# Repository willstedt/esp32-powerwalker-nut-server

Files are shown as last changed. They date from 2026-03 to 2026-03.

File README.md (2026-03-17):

# BlueWalker Online
**BlueWalker Online** konverterar en ESP32-S3 till en NUT-server för Powerwalker UPS.  Då kan Unifi läsa UPS-data och alla datorer i nätverket kan ta del av UPS-information.

# Vad som behövs för att sätta upp en NUT-server
Du behöver ha en ESP32-S3 med dubbla USB-portar  
Den väntra USB-porten används för att ge ström och ladda upp projekt-uppdateringar.  
Den högra USB-porten används för att läsa data från Powerwalkern.

**Viktigt:** Du behöver löda +5V från ESP32:an till de stora benen till höger eller vänster på ESP32:ans högra USB-port eftersom ESP32 inte skickar ut 5V till USB-porten (den är USB-slav och det är bara USB-masters som skickar ut 5V). Därför behöver du ta 5V från ESP32 och skicka ut på ena benet.

Montera en liten OLED-skärm 128x64 (med fyra pinnar: 3V3, GND, SDA och SCL). Den visar vilken IP-adress enheten fått samt batteriprocent.  

`SDA = GPIO 8`  
`SCL = GPIO 9`

Montera en liten tryckknapp för att resetta enheten, samt i framtiden kunna ändra wifi-inställningar etc.
Tryckknappen ska kopplas mot `SDA = GPIO 10` och `GND`.  
  
STL för att 3D-printa box och lock:  
[Box](BlueWalker Connect Case.stl)  
[Lock](Bluewalker Connect Lid.stl)  

# Användning
**NUT:** UPS-servern använder sig av NUT (Network UPS Tools) som gör att enheter på nätverket kan få information från UPS:en.

För att kunna läsa UPS-information från NUT-servern – installera **nut** (`brew install nut`).
För att Mac ska övervaka UPS via NUT, kör `upsc ups@[IP]`. Exempelvis `upsc ups@10.21.0.136`.

**SNMP:** Enheten har också en SNMP-agent på port 161 som gör att Unifi och andra enheter som scannar SNMP automatiskt kan hitta den.

**WEBB:** BlueWalker Online har också en inbyggd webbserver så att du kan få information via en vanlig webbläsare.

**Komplett enhet:**  
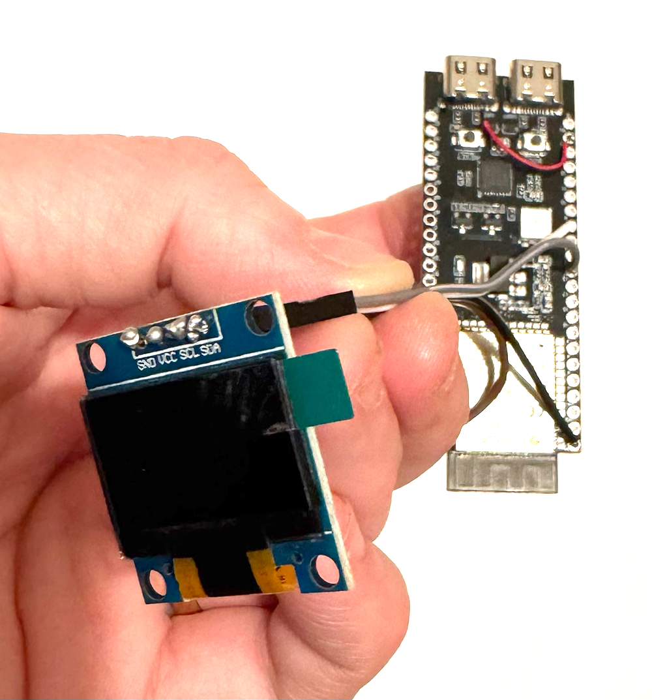
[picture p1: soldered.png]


**Lödning:**  
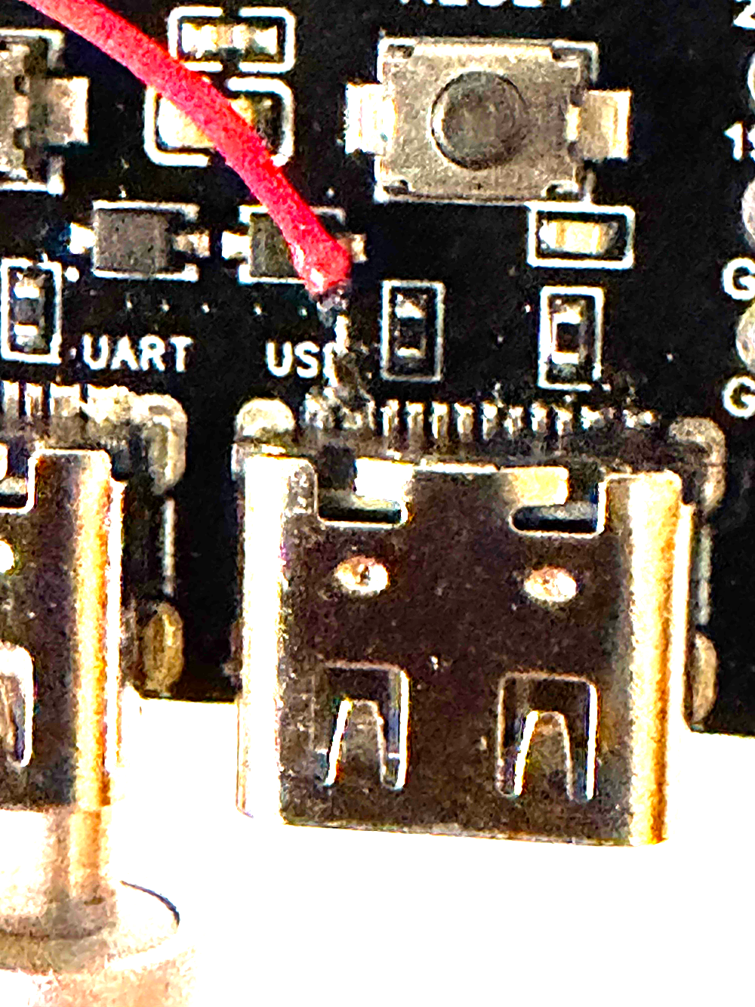
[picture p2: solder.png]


**Enhet:**  
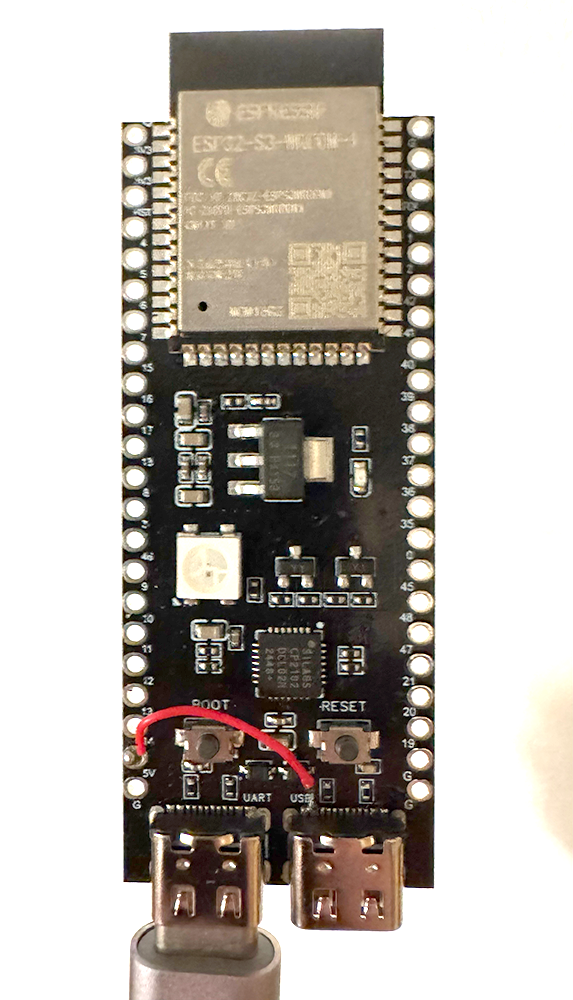
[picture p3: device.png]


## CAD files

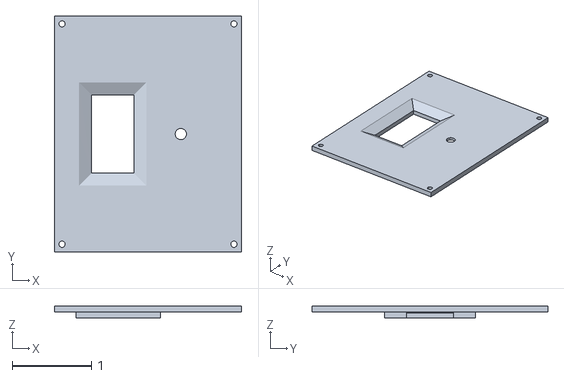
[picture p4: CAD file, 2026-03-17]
Bluewalker Connect Lid.stl
2.36 x 2.97 x 0.157

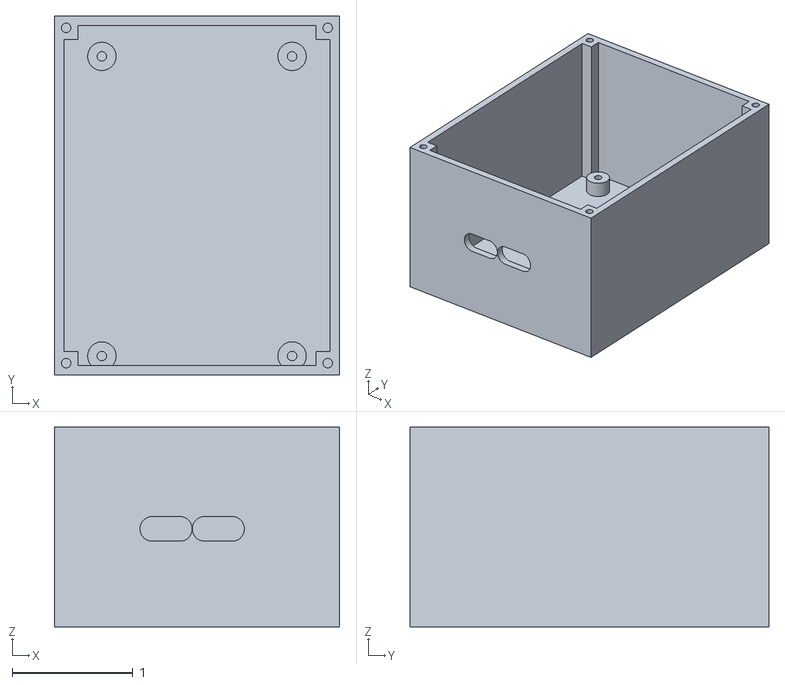
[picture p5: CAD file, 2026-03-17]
BlueWalker Connect Case.stl
2.36 x 2.97 x 1.65

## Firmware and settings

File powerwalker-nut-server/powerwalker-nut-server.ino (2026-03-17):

#include <Arduino.h>
#include <string.h>
#include <WiFi.h>
#include <WiFiUdp.h>
#include <WebServer.h>
#include <Wire.h>
#include <Adafruit_GFX.h>
#include <Adafruit_SSD1306.h>

#include "usb/usb_host.h"
#include "usb/usb_types_ch9.h"

// ============================================================
// USER SETTINGS
// ============================================================
const char *WIFI_SSID = "willstedt";
const char *WIFI_PASSWORD = "will13734";
const char *NUT_UPS_NAME = "ups";
const char *SNMP_COMMUNITY = "public";

const char *DEVICE_MFR = "BlueWalker";
const char *DEVICE_MODEL = "BlueWalker Online";
const char *DEVICE_DESC = "BlueWalker Online";
const char *DRIVER_NAME = "esp32-usb-ups";
const char *DRIVER_VERSION = "0.5";

// These are still partial estimates until more USB tags are decoded
const int DEFAULT_LOAD_PERCENT = 11;
const int DEFAULT_OUTPUT_VOLTAGE = 230;

// ============================================================
// OLED SETTINGS
// ============================================================
const int OLED_WIDTH = 128;
const int OLED_HEIGHT = 64;
const int OLED_RESET = -1;
const uint8_t OLED_ADDR = 0x3C;

// Your wiring
const int OLED_SDA = 8;
const int OLED_SCL = 9;

Adafruit_SSD1306 display(OLED_WIDTH, OLED_HEIGHT, &Wire, OLED_RESET);
bool oledReady = false;
unsigned long lastDisplayUpdateMs = 0;

// ============================================================
// USB / UPS IDs
// ============================================================
static const uint16_t UPS_VID = 0x0665;
static const uint16_t UPS_PID = 0x5161;
static const uint8_t EP1 = 0x81;
static const uint8_t EP2 = 0x82;
static const size_t REPORT_SIZE = 8;

// ============================================================
// NETWORK SERVICES
// ============================================================
WebServer httpServer(80);
WiFiServer nutServer(3493);
WiFiUDP snmpUdp;

// ============================================================
// USB GLOBALS
// ============================================================
usb_host_client_handle_t g_client = nullptr;
usb_device_handle_t g_dev_hdl = nullptr;
usb_transfer_t *g_xfer81 = nullptr;
usb_transfer_t *g_xfer82 = nullptr;

volatile uint8_t g_dev_addr = 0;
volatile bool g_dev_present = false;
bool g_claimed = false;

// ============================================================
// UPS STATE
// ============================================================
struct UpsState {
  bool have_flags = false;
  bool have_charge = false;
  bool have_metric = false;

  uint32_t flags = 0;          // tag 0x32
  uint8_t charge_percent = 0;  // tag 0x34
  uint16_t battery_metric = 0; // tag 0x35

  unsigned long last_flags_ms = 0;
  unsigned long last_charge_ms = 0;
  unsigned long last_metric_ms = 0;

  unsigned long battery_start_ms = 0;
};

UpsState g_state;
UpsState g_last_printed;

bool g_have_last_metric_logged = false;
uint16_t g_last_metric_logged = 0;
unsigned long g_last_metric_log_ms = 0;
unsigned long g_device_open_ms = 0;
unsigned long g_last_any_packet_ms = 0;
bool g_have_seen_any_packet = false;

struct LastUnknown {
  bool valid = false;
  uint8_t tag = 0;
  uint8_t len = 0;
  uint8_t data[8] = {0};
};

LastUnknown g_last_unknown_81;
LastUnknown g_last_unknown_82;

// ============================================================
// SNMP TYPES
// ============================================================
struct SnmpOidEntry {
  const uint32_t *oid;
  size_t oidLen;
};

enum SnmpValueType {
  SVT_INTEGER,
  SVT_STRING,
  SVT_TIMETICKS
};

struct SnmpValue {
  SnmpValueType type;
  int32_t intValue;
  String strValue;
};

// ============================================================
// SNMP OIDs
// ============================================================
static const uint32_t OID_sysDescr[]                 = {1, 3, 6, 1, 2, 1, 1, 1, 0};
static const uint32_t OID_sysUpTime[]                = {1, 3, 6, 1, 2, 1, 1, 3, 0};

static const uint32_t OID_upsIdentManufacturer[]     = {1, 3, 6, 1, 2, 1, 33, 1, 1, 1, 0};
static const uint32_t OID_upsIdentModel[]            = {1, 3, 6, 1, 2, 1, 33, 1, 1, 2, 0};
static const uint32_t OID_upsIdentSoftwareVersion[]  = {1, 3, 6, 1, 2, 1, 33, 1, 1, 3, 0};

static const uint32_t OID_upsBatteryStatus[]         = {1, 3, 6, 1, 2, 1, 33, 1, 2, 1, 0};
static const uint32_t OID_upsSecondsOnBattery[]      = {1, 3, 6, 1, 2, 1, 33, 1, 2, 2, 0};
static const uint32_t OID_upsEstimatedMinutes[]      = {1, 3, 6, 1, 2, 1, 33, 1, 2, 3, 0};
static const uint32_t OID_upsEstimatedCharge[]       = {1, 3, 6, 1, 2, 1, 33, 1, 2, 4, 0};

static const uint32_t OID_upsInputNumLines[]         = {1, 3, 6, 1, 2, 1, 33, 1, 3, 2, 0};
static const uint32_t OID_upsInputVoltage[]          = {1, 3, 6, 1, 2, 1, 33, 1, 3, 3, 1, 3, 1};

static const uint32_t OID_upsOutputSource[]          = {1, 3, 6, 1, 2, 1, 33, 1, 4, 1, 0};
static const uint32_t OID_upsOutputVoltage[]         = {1, 3, 6, 1, 2, 1, 33, 1, 4, 2, 1, 2, 1};
static const uint32_t OID_upsOutputPercentLoad[]     = {1, 3, 6, 1, 2, 1, 33, 1, 4, 4, 1, 5, 1};

static const SnmpOidEntry SNMP_OIDS[] = {
  {OID_sysDescr, sizeof(OID_sysDescr) / sizeof(uint32_t)},
  {OID_sysUpTime, sizeof(OID_sysUpTime) / sizeof(uint32_t)},
  {OID_upsIdentManufacturer, sizeof(OID_upsIdentManufacturer) / sizeof(uint32_t)},
  {OID_upsIdentModel, sizeof(OID_upsIdentModel) / sizeof(uint32_t)},
  {OID_upsIdentSoftwareVersion, sizeof(OID_upsIdentSoftwareVersion) / sizeof(uint32_t)},
  {OID_upsBatteryStatus, sizeof(OID_upsBatteryStatus) / sizeof(uint32_t)},
  {OID_upsSecondsOnBattery, sizeof(OID_upsSecondsOnBattery) / sizeof(uint32_t)},
  {OID_upsEstimatedMinutes, sizeof(OID_upsEstimatedMinutes) / sizeof(uint32_t)},
  {OID_upsEstimatedCharge, sizeof(OID_upsEstimatedCharge) / sizeof(uint32_t)},
  {OID_upsInputNumLines, sizeof(OID_upsInputNumLines) / sizeof(uint32_t)},
  {OID_upsInputVoltage, sizeof(OID_upsInputVoltage) / sizeof(uint32_t)},
  {OID_upsOutputSource, sizeof(OID_upsOutputSource) / sizeof(uint32_t)},
  {OID_upsOutputVoltage, sizeof(OID_upsOutputVoltage) / sizeof(uint32_t)},
  {OID_upsOutputPercentLoad, sizeof(OID_upsOutputPercentLoad) / sizeof(uint32_t)},
};

// ============================================================
// HELPERS
// ============================================================
static void print_hex(const uint8_t *buf, size_t len) {
  for (size_t i = 0; i < len; ++i) {
    Serial.printf("%02X ", buf[i]);
  }
}

static bool is_on_battery_flags(uint32_t flags) {
  return flags == 0x002000;
}

static bool is_on_mains_flags(uint32_t flags) {
  return flags == 0x112000;
}

static bool is_switching_flags(uint32_t flags) {
  return flags == 0x102000 || flags == 0x012000;
}

static bool isUpsUsbConnected() {
  return g_dev_present;
}

static const char *power_state_text(uint32_t flags) {
  if (is_on_mains_flags(flags)) return "ON MAINS";
  if (is_on_battery_flags(flags)) return "ON BATTERY";
  if (is_switching_flags(flags)) return "SWITCHING";
  return "UNKNOWN";
}

static String shortPowerState() {
  if (!g_state.have_flags) return "WAIT";
  if (is_on_mains_flags(g_state.flags)) return "ON MAINS";
  if (is_on_battery_flags(g_state.flags)) return "ON BATTERY";
  if (is_switching_flags(g_state.flags)) return "SWITCHING";
  return "UNKNOWN";
}

static String nut_status() {
  if (!g_state.have_flags) return "WAIT";
  if (is_on_mains_flags(g_state.flags)) return "OL CHRG";
  if (is_on_battery_flags(g_state.flags)) return "OB DISCHRG";
  if (is_switching_flags(g_state.flags)) return "OB";
  return "WAIT";
}

static int estimated_load_percent() {
  return DEFAULT_LOAD_PERCENT;
}

static float estimated_output_voltage() {
  return DEFAULT_OUTPUT_VOLTAGE;
}

static float estimated_input_voltage() {
  if (is_on_mains_flags(g_state.flags)) return DEFAULT_OUTPUT_VOLTAGE;
  return 0.0f;
}

static int estimated_minutes_remaining() {
  if (!g_state.have_charge) return 0;
  int mins = (int)round(g_state.charge_percent * 0.53f);
  if (mins < 1) mins = 1;
  return mins;
}

static uint32_t seconds_on_battery() {
  if (!g_state.have_flags || !is_on_battery_flags(g_state.flags) || g_state.battery_start_ms == 0) {
    return 0;
  }
  return (millis() - g_state.battery_start_ms) / 1000UL;
}

static int snmp_battery_status() {
  if (!g_state.have_flags) return 1;
  if (is_on_battery_flags(g_state.flags) && g_state.have_charge && g_state.charge_percent <= 20) return 3;
  return 2;
}

static int snmp_output_source() {
  if (!g_state.have_flags) return 1;
  if (is_on_mains_flags(g_state.flags)) return 3;
  if (is_on_battery_flags(g_state.flags)) return 5;
  return 1;
}

static bool same_state(const UpsState &a, const UpsState &b) {
  return memcmp(&a, &b, sizeof(UpsState)) == 0;
}

static String statusColor() {
  if (!g_state.have_flags) return "#6b7280";
  if (is_on_mains_flags(g_state.flags)) return "#10b981";
  if (is_on_battery_flags(g_state.flags)) return "#f59e0b";
  if (is_switching_flags(g_state.flags)) return "#3b82f6";
  return "#ef4444";
}

static String htmlIconPower() {
  if (is_on_mains_flags(g_state.flags)) {
    return "<svg viewBox='0 0 24 24' fill='none' stroke='currentColor' stroke-width='2'><path d='M7 2v6'/><path d='M17 2v6'/><path d='M6 8h12v6a6 6 0 0 1-12 0V8z'/></svg>";
  }
  if (is_on_battery_flags(g_state.flags)) {
    return "<svg viewBox='0 0 24 24' fill='none' stroke='currentColor' stroke-width='2'><rect x='2' y='7' width='18' height='10' rx='2'/><path d='M22 10v4'/><path d='M6 10l3 4 2-3 2 3 3-4'/></svg>";
  }
  return "<svg viewBox='0 0 24 24' fill='none' stroke='currentColor' stroke-width='2'><path d='M13 2L4 14h6l-1 8 9-12h-6l1-8z'/></svg>";
}

static String htmlIconBattery() {
  return "<svg viewBox='0 0 24 24' fill='none' stroke='currentColor' stroke-width='2'><rect x='2' y='7' width='18' height='10' rx='2'/><path d='M22 10v4'/></svg>";
}

static String htmlIconLoad() {
  return "<svg viewBox='0 0 24 24' fill='none' stroke='currentColor' stroke-width='2'><path d='M4 18h16'/><path d='M7 18V9'/><path d='M12 18V5'/><path d='M17 18v-7'/></svg>";
}

static String htmlIconClock() {
  return "<svg viewBox='0 0 24 24' fill='none' stroke='currentColor' stroke-width='2'><circle cx='12' cy='12' r='9'/><path d='M12 7v5l3 3'/></svg>";
}

static String htmlIconWifi() {
  return "<svg viewBox='0 0 24 24' fill='none' stroke='currentColor' stroke-width='2'><path d='M5 12.55a11 11 0 0 1 14.08 0'/><path d='M1.42 9a16 16 0 0 1 21.16 0'/><path d='M8.53 16.11a6 6 0 0 1 6.95 0'/><path d='M12 20h.01'/></svg>";
}

static void maybe_log_metric() {
  if (!g_state.have_metric) return;

  const unsigned long now = millis();
  const bool first = !g_have_last_metric_logged;
  const bool enough_time = (now - g_last_metric_log_ms) >= 5000;
  const bool enough_change = first || abs((int)g_state.battery_metric - (int)g_last_metric_logged) >= 5;

  if (enough_time || enough_change) {
    Serial.printf("[%10lu ms] BATTERY_METRIC UPDATE: %u (0x%04X, %.3f)\n",
                  now,
                  g_state.battery_metric,
                  g_state.battery_metric,
                  g_state.battery_metric / 1000.0f);

    g_last_metric_logged = g_state.battery_metric;
    g_have_last_metric_logged = true;
    g_last_metric_log_ms = now;
  }
}

static void print_summary(const char *reason) {
  UpsState tmp = g_state;
  tmp.last_flags_ms = 0;
  tmp.last_charge_ms = 0;
  tmp.last_metric_ms = 0;

  UpsState last = g_last_printed;
  last.last_flags_ms = 0;
  last.last_charge_ms = 0;
  last.last_metric_ms = 0;

  if (same_state(tmp, last)) return;
  g_last_printed = g_state;

  Serial.println();
  Serial.println("========================================");
  Serial.printf("[%10lu ms] UPS SUMMARY (%s)\n", millis(), reason);

  if (g_state.have_flags) {
    Serial.printf("PowerState     : %s\n", power_state_text(g_state.flags));
    Serial.printf("Flags          : 0x%06lX\n", (unsigned long)g_state.flags);
    Serial.printf("NUT status     : %s\n", nut_status().c_str());
  } else {
    Serial.println("PowerState     : unknown");
    Serial.println("Flags          : unknown");
    Serial.println("NUT status     : WAIT");
  }

  if (g_state.have_charge) {
    Serial.printf("ChargePercent  : %u %%\n", g_state.charge_percent);
  } else {
    Serial.println("ChargePercent  : unknown");
  }

  if (g_state.have_metric) {
    Serial.printf("BatteryMetric  : %u (0x%04X)\n", g_state.battery_metric, g_state.battery_metric);
    Serial.printf("Metric/1000    : %.3f\n", g_state.battery_metric / 1000.0f);
  } else {
    Serial.println("BatteryMetric  : unknown");
  }

  Serial.printf("LoadEstimate   : %d %%\n", estimated_load_percent());
  Serial.printf("OutputVoltage  : %.1f V\n", estimated_output_voltage());
  Serial.printf("InputVoltage   : %.1f V\n", estimated_input_voltage());
  Serial.printf("MinutesRemain  : %d\n", estimated_minutes_remaining());

  Serial.println("========================================");
}

// ============================================================
// OLED DRAWING
// ============================================================
static void drawPlugIcon(int x, int y) {
  display.drawRect(x + 6, y + 8, 16, 12, SSD1306_WHITE);
  display.drawLine(x + 10, y + 3, x + 10, y + 8, SSD1306_WHITE);
  display.drawLine(x + 18, y + 3, x + 18, y + 8, SSD1306_WHITE);
  display.drawLine(x + 14, y + 20, x + 14, y + 27, SSD1306_WHITE);
  display.drawLine(x + 14, y + 27, x + 10, y + 31, SSD1306_WHITE);
}

static void drawBatteryIcon(int x, int y, int pct) {
  display.drawRoundRect(x, y + 6, 24, 12, 2, SSD1306_WHITE);
  display.drawRect(x + 24, y + 9, 3, 6, SSD1306_WHITE);

  int fill = map(pct, 0, 100, 0, 20);
  if (fill < 0) fill = 0;
  if (fill > 20) fill = 20;
  if (fill > 0) {
    display.fillRect(x + 2, y + 8, fill, 8, SSD1306_WHITE);
  }
}

static void drawSwitchingIcon(int x, int y) {
  display.drawLine(x + 12, y + 0, x + 5, y + 13, SSD1306_WHITE);
  display.drawLine(x + 5, y + 13, x + 11, y + 13, SSD1306_WHITE);
  display.drawLine(x + 11, y + 13, x + 9, y + 26, SSD1306_WHITE);
  display.drawLine(x + 9, y + 26, x + 19, y + 10, SSD1306_WHITE);
  display.drawLine(x + 19, y + 10, x + 13, y + 10, SSD1306_WHITE);
}

static void drawUsbIcon(int x, int y) {
  display.drawCircle(x + 12, y + 4, 2, SSD1306_WHITE);
  display.drawLine(x + 12, y + 6, x + 12, y + 18, SSD1306_WHITE);
  display.drawLine(x + 12, y + 10, x + 7, y + 15, SSD1306_WHITE);
  display.drawLine(x + 12, y + 10, x + 17, y + 15, SSD1306_WHITE);
  display.drawTriangle(x + 10, y + 18, x + 14, y + 18, x + 12, y + 22, SSD1306_WHITE);
  display.drawRect(x + 5, y + 14, 4, 4, SSD1306_WHITE);
  display.drawCircle(x + 18, y + 16, 2, SSD1306_WHITE);
}

static void drawBatteryBar(int x, int y, int w, int h, int pct) {
  display.drawRoundRect(x, y, w, h, 3, SSD1306_WHITE);
  display.drawRect(x + w, y + (h / 2) - 3, 3, 6, SSD1306_WHITE);

  int innerW = w - 4;
  int fill = map(pct, 0, 100, 0, innerW);
  if (fill < 0) fill = 0;
  if (fill > innerW) fill = innerW;
  if (fill > 0) {
    display.fillRoundRect(x + 2, y + 2, fill, h - 4, 2, SSD1306_WHITE);
  }
}

static void setupDisplay() {
  Wire.begin(OLED_SDA, OLED_SCL);

  if (!display.begin(SSD1306_SWITCHCAPVCC, OLED_ADDR)) {
    Serial.println("OLED init failed");
    oledReady = false;
    return;
  }

  oledReady = true;
  display.clearDisplay();
  display.setTextColor(SSD1306_WHITE);
  display.setTextSize(1);
  display.setCursor(0, 0);
  display.println("BlueWalker Online");
  display.setCursor(0, 16);
  display.println("Booting...");
  display.display();
}

static void updateDisplay() {
  if (!oledReady) return;
  if (millis() - lastDisplayUpdateMs < 500) return;
  lastDisplayUpdateMs = millis();

  display.clearDisplay();
  display.setTextColor(SSD1306_WHITE);

  display.setTextSize(1);
  display.setCursor(0, 0);
  display.print("BlueWalker Online");

  display.setCursor(0, 10);
  display.print("IP:");
  display.print(WiFi.localIP());

  if (!isUpsUsbConnected()) {
    drawUsbIcon(2, 26);

    display.setTextSize(1);
    display.setCursor(32, 28);
    display.println("USB CONNECTION");

    display.setCursor(32, 38);
    display.println("MISSING");

    display.setCursor(0, 56);
    display.print("Connect BlueWalker USB");
    display.display();
    return;
  }

  if (g_state.have_flags) {
    if (is_on_mains_flags(g_state.flags)) {
      drawPlugIcon(2, 24);
    } else if (is_on_battery_flags(g_state.flags)) {
      drawBatteryIcon(2, 24, g_state.have_charge ? g_state.charge_percent : 0);
    } else {
      drawSwitchingIcon(2, 24);
    }
  } else {
    drawSwitchingIcon(2, 24);
  }

  display.setTextSize(1);
  display.setCursor(32, 24);
  display.print(shortPowerState());

  display.setTextSize(2);
  display.setCursor(32, 36);
  if (g_state.have_charge) {
    display.print(g_state.charge_percent);
    display.print("%");
  } else {
    display.print("--%");
  }

  int pct = g_state.have_charge ? g_state.charge_percent : 0;
  drawBatteryBar(2, 52, 70, 10, pct);

  display.setTextSize(1);
  display.setCursor(78, 54);
  display.print(estimated_minutes_remaining());
  display.print(" min");

  display.display();
}

// ============================================================
// UNKNOWN TAG MEMORY
// ============================================================
static void maybe_log_unknown(uint8_t ep, const uint8_t *buf, uint8_t len) {
  LastUnknown *slot = (ep == EP1) ? &g_last_unknown_81 : &g_last_unknown_82;

  if (slot->valid &&
      slot->tag == buf[0] &&
      slot->len == len &&
      memcmp(slot->data, buf, len) == 0) {
    return;
  }

  slot->valid = true;
  slot->tag = buf[0];
  slot->len = len;
  memset(slot->data, 0, sizeof(slot->data));
  memcpy(slot->data, buf, len);

  Serial.printf("[%10lu ms] UNKNOWN TAG on EP 0x%02X len=%u data=",
                millis(), ep, len);
  print_hex(buf, len);
  Serial.println();
}

// ============================================================
// USB PACKET PARSING
// ============================================================
static void handle_packet(uint8_t ep, const uint8_t *buf, uint8_t len) {
  if (len < 2) return;

  g_have_seen_any_packet = true;
  g_last_any_packet_ms = millis();
  Serial.printf("[%10lu ms] PKT EP 0x%02X len=%u tag=0x%02X data=", millis(), ep, len, buf[0]);
  print_hex(buf, len);
  Serial.println();

  switch (buf[0]) {
    case 0x32: {
      if (len >= 4) {
        uint32_t new_flags = (uint32_t)buf[1]
                           | ((uint32_t)buf[2] << 8)
                           | ((uint32_t)buf[3] << 16);

        if (!g_state.have_flags || g_state.flags != new_flags) {
          bool was_on_battery = g_state.have_flags && is_on_battery_flags(g_state.flags);
          bool now_on_battery = is_on_battery_flags(new_flags);

          g_state.flags = new_flags;
          g_state.have_flags = true;
          g_state.last_flags_ms = millis();

          if (!was_on_battery && now_on_battery) {
            g_state.battery_start_ms = millis();
          } else if (was_on_battery && !now_on_battery) {
            g_state.battery_start_ms = 0;
          }

          print_summary("flags changed");
          updateDisplay();
        }
      }
      break;
    }

    case 0x34: {
      if (len >= 2) {
        uint8_t new_charge = buf[1];
        if (!g_state.have_charge || g_state.charge_percent != new_charge) {
          g_state.charge_percent = new_charge;
          g_state.have_charge = true;
          g_state.last_charge_ms = millis();
          print_summary("charge changed");
          updateDisplay();
        }
      }
      break;
    }

    case 0x35: {
      if (len >= 3) {
        uint16_t new_metric = (uint16_t)buf[1] | ((uint16_t)buf[2] << 8);
        g_state.battery_metric = new_metric;
        g_state.have_metric = true;
        g_state.last_metric_ms = millis();
        maybe_log_metric();
      }
      break;
    }

    default:
      maybe_log_unknown(ep, buf, len);
      break;
  }
}

static void transfer_cb(usb_transfer_t *transfer) {
  if (transfer->status == USB_TRANSFER_STATUS_COMPLETED &&
      transfer->actual_num_bytes > 0) {
    handle_packet(transfer->bEndpointAddress, transfer->data_buffer, transfer->actual_num_bytes);
  } else if (transfer->status != USB_TRANSFER_STATUS_COMPLETED) {
    Serial.printf("[%10lu ms] EP 0x%02X transfer error: %d\n",
                  millis(), transfer->bEndpointAddress, transfer->status);
  }

  memset(transfer->data_buffer, 0, transfer->num_bytes);
  esp_err_t err = usb_host_transfer_submit(transfer);
  if (err != ESP_OK) {
    Serial.printf("[%10lu ms] Resubmit failed on EP 0x%02X: %d\n",
                  millis(), transfer->bEndpointAddress, err);
  }
}

static esp_err_t start_interrupt_in(usb_transfer_t **xfer,
                                    usb_device_handle_t dev_hdl,
                                    uint8_t ep_addr,
                                    size_t size) {
  esp_err_t err = usb_host_transfer_alloc(size, 0, xfer);
  if (err != ESP_OK) {
    Serial.printf("usb_host_transfer_alloc failed for EP 0x%02X: %d\n", ep_addr, err);
    return err;
  }

  (*xfer)->device_handle = dev_hdl;
  (*xfer)->bEndpointAddress = ep_addr;
  (*xfer)->callback = transfer_cb;
  (*xfer)->context = nullptr;
  (*xfer)->num_bytes = size;
  memset((*xfer)->data_buffer, 0, size);

  err = usb_host_transfer_submit(*xfer);
  if (err != ESP_OK) {
    Serial.printf("usb_host_transfer_submit failed for EP 0x%02X: %d\n", ep_addr, err);
    return err;
  }

  Serial.printf("[%10lu ms] Started listening on EP 0x%02X\n", millis(), ep_addr);
  return ESP_OK;
}

static void resetUpsState() {
  memset(&g_state, 0, sizeof(g_state));
  memset(&g_last_printed, 0, sizeof(g_last_printed));
  g_have_last_metric_logged = false;
  g_last_metric_logged = 0;
  g_last_metric_log_ms = 0;
  g_device_open_ms = 0;
  g_last_any_packet_ms = 0;
  g_have_seen_any_packet = false;
}
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
void loop() {
  httpServer.handleClient();
  handleNutClients();
  handleSnmpPacket();
  updateDisplay();
  delay(2);
}

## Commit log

2026-03-11 Making the powerwalker a nut server
2026-03-11 Fixed the Wifi password
    [powerwalker-nut-server.ino]
2026-03-13 Updated to support having the USB cable connected after the device was turned on
2026-03-17 STL-filer för låda
    [BlueWalker Connect Case.stl, Bluewalker Connect Lid.stl]
